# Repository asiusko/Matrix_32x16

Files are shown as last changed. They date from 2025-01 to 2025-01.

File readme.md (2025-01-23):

# The ESP32 based spectrum analyzer 32x16 LED matrix VU meter

### Main components:
 - Controller ESP32 WROOM-32D
 - Touch sensor TTP223B
 - Microphone Amplifier MAX9814 (with Auto Gain Control)
 - Rotary encoder
 - OLED I2C screen 128x64
 - WS2812B (two 16x16 zig-zag matrix) 

The controller can handle a few separate led strips or matrix. 
The current schema and code can handle 4 strips/matrix.

Please be careful with a power supply, it should provide enough power to supply the leds. 
Each LED draws about 50mA, when set to its full brightness. 
This means that for every 30 LEDs, the strip may draw as much as 1.5 A.
The matrix 16x32 contains 512 LEDs and needs 25A to show the full brightness.
You can restrict the max current for a strip/matrix on the program level. 

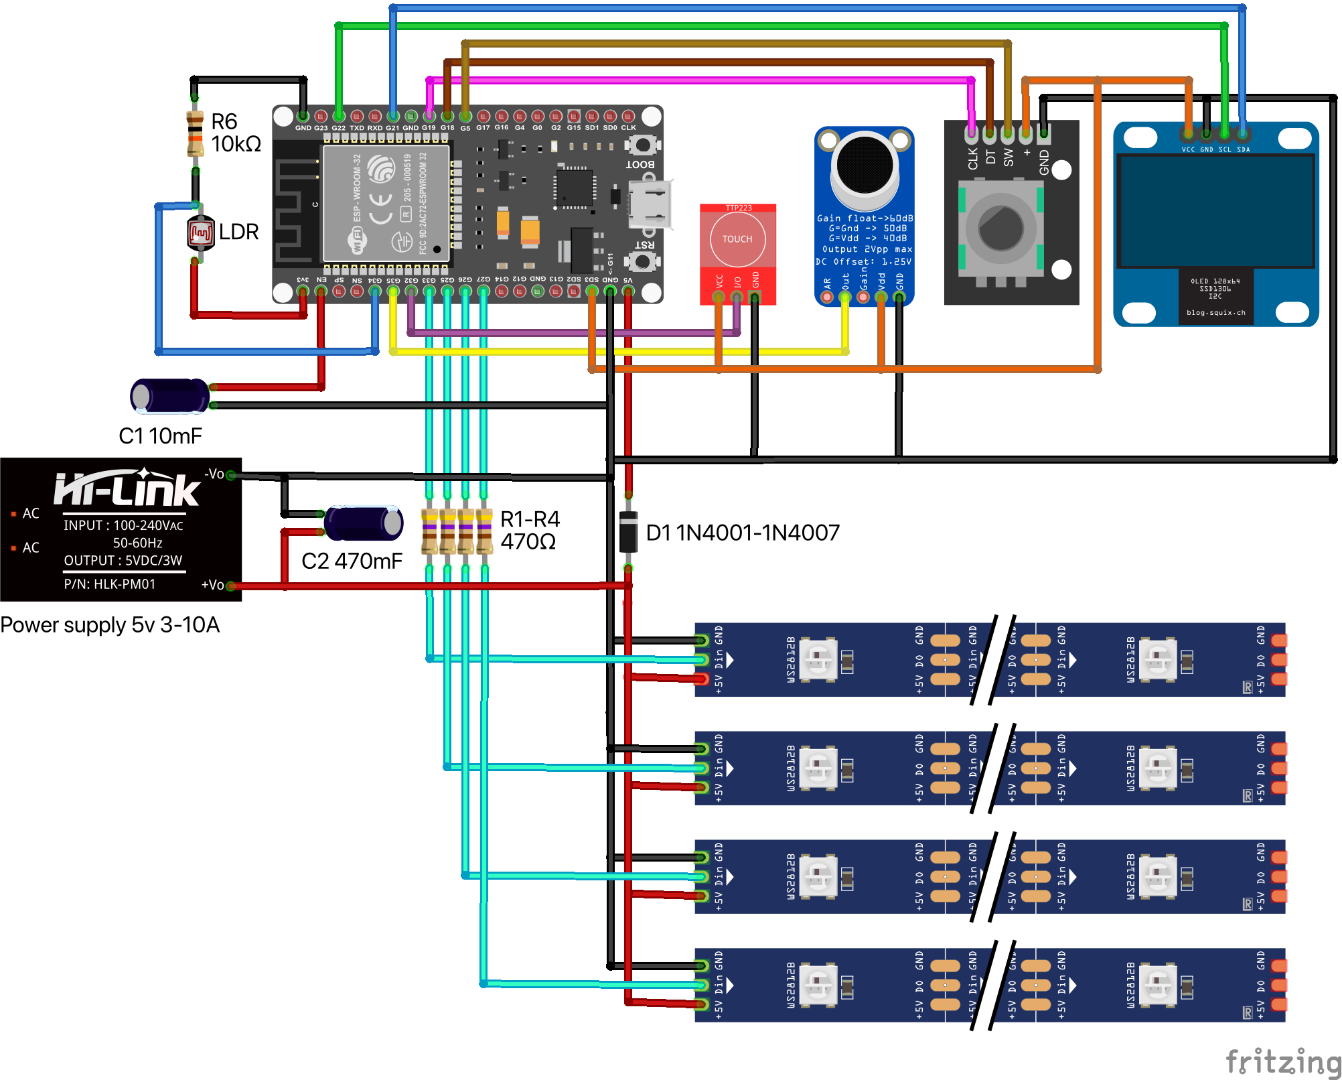
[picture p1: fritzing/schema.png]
Main schema


- Capacitor C1 10mF - to avoid the boot btn press during firmware uploading.
- Capacitor C2 470mf - power supply noise filter.
- Resistors R1-R4 330Ω–470Ω - protection resistors, place the resistors as close as possible to the ESP32 pin for maximum effectiveness (voltage spikes can damage the first LED in the chain or cause erratic behavior)  
- Diode D1 1N4001-1N4007 - to prevent LEDs power supply from USB port during firmware update.
- R6-LDR resistors (voltage divider schema) are used take a light value on the analog pin. ADC resolution - 12 bits (values from 0 to 4095). 

### Images: 
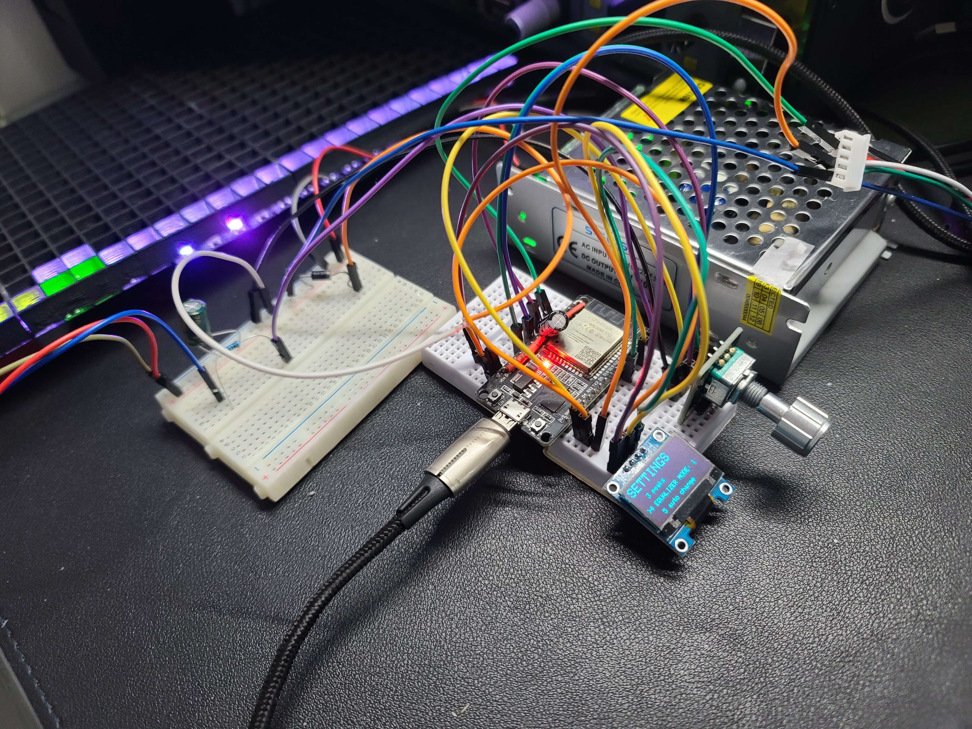
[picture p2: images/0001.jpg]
prototype

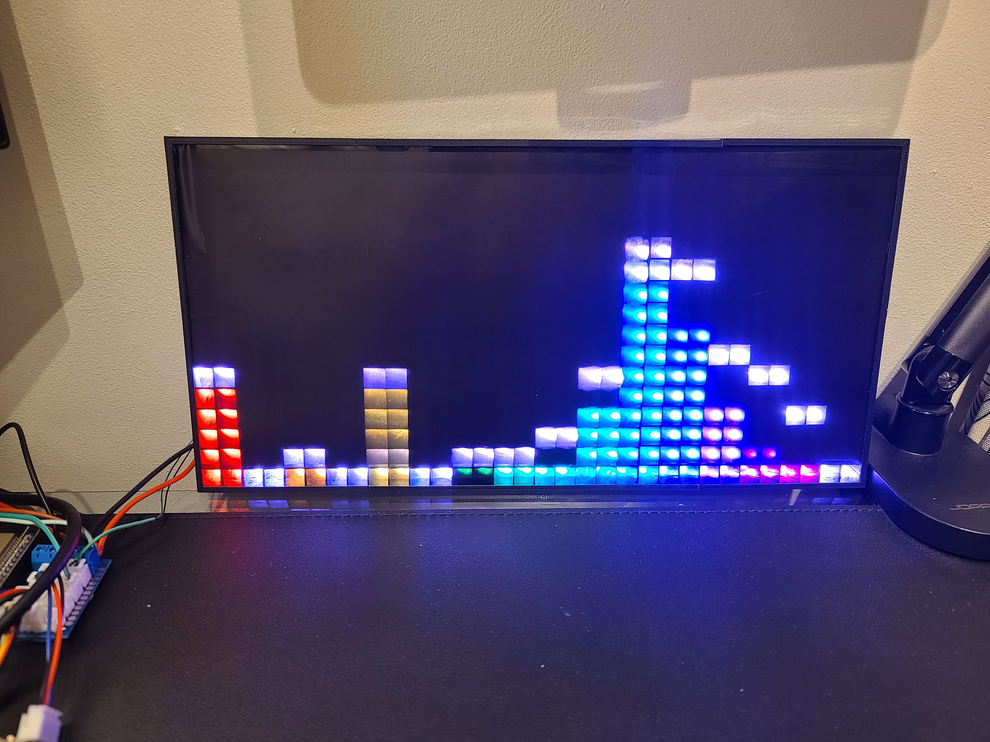
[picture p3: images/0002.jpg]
matrix

components

### Notes: 
- Please use **[sample_test.ino](tools/sampleTest/sample_test.ino)** and **[FFT.xlsx](tools/sampleTest/FFT.xlsx)** to calculate Band values based on the microcontroller ADC speed.
- If failed to mount SPIFFS file system. Run **[formatSPIFFS.ino](tools/formatSPIFFS/formatSPIFFS.ino)**
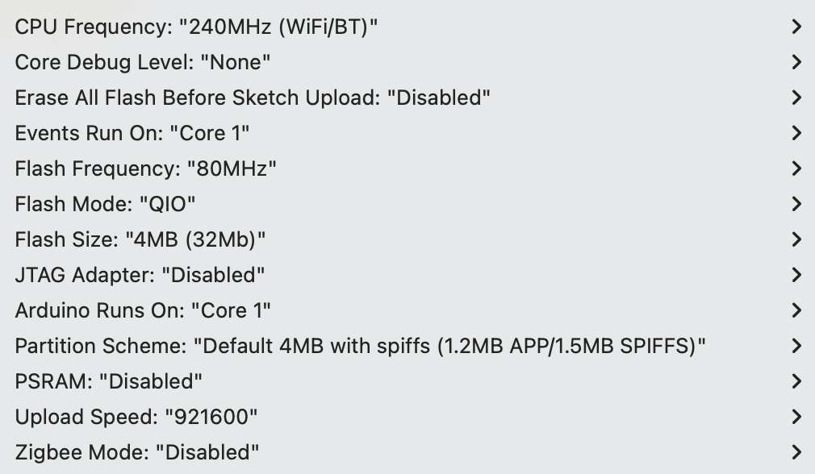
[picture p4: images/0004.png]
configuration
- ESP-WROOM-32D configuration 

### WiFi and WEB
- The ESP initially loads WiFi access point with predefined SSID and PASS check AP_WIFI_SSID and AP_WIFI_PASSWORD.
- In serial logs you can see the IP address, usually its 192.168.4.1
- To connect to the wifi just enter ssid and pass which will be saved in the internal memory for future connections.
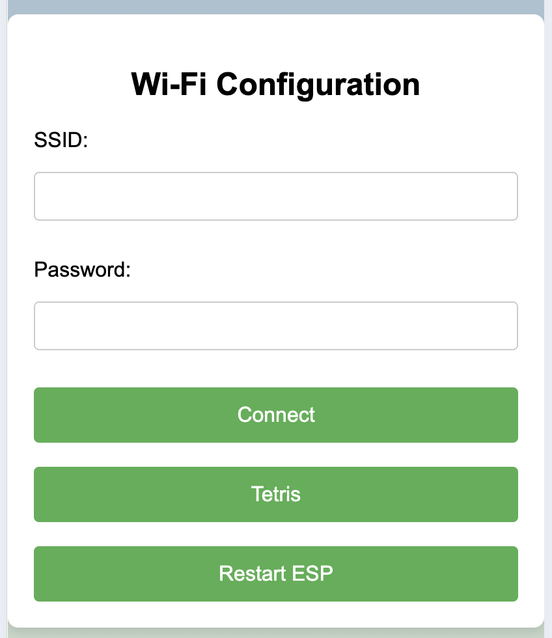
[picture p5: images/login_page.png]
login_page

- Tetris will start the game on the matrix and navigate to the control joystick, please use a mobile horizontal mode to display it correctly(TODO responsive design).
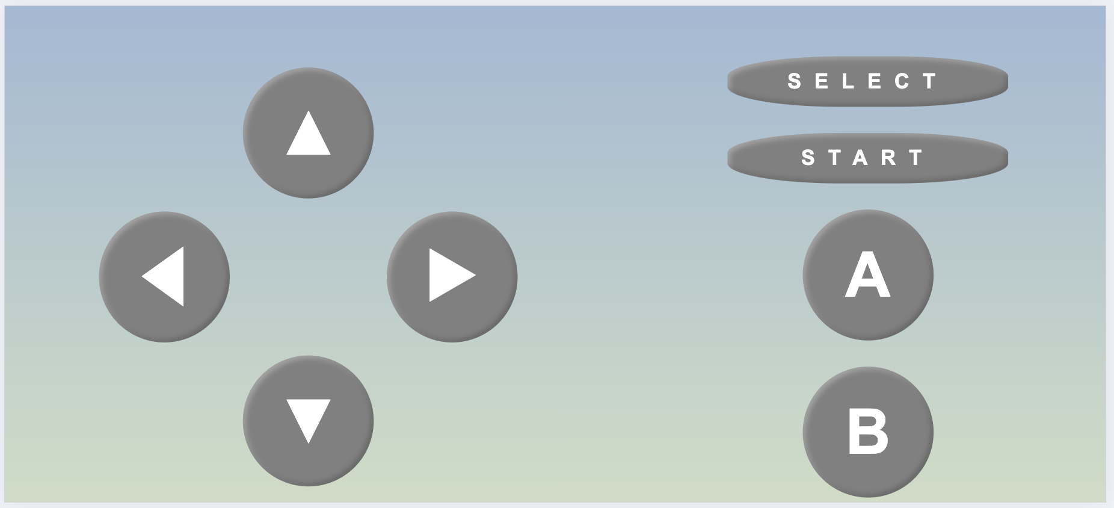
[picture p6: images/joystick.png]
joystick


### TODO:
- Sound output
- Vertical/Horizontal mode
- Connect with the home weather station
- Games
- More effects
- Responsive design and more controls from WEB
- Documentation

### License

This project is licensed under the Apache License, Version 2.0.

You are free to use, modify, and distribute this software under the terms of the Apache 2.0 License. See the [LICENSE](LICENSE.txt) file for details.

#### Key Points:
- **Attribution**: You must give proper credit to the original author(s).
- **Modifications**: If you modify the code, you must clearly indicate what changes were made.
- **No Liability**: The software is provided "as-is" without any warranty.

For more information, refer to the full [Apache 2.0 License](https://www.apache.org/licenses/LICENSE-2.0).

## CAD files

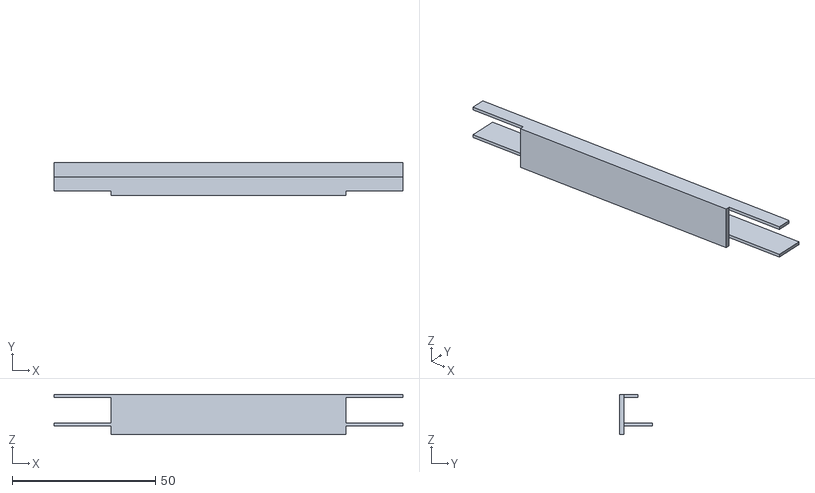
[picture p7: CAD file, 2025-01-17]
stl/32x16_frame_2.stl
122.0 x 11.5 x 14.0

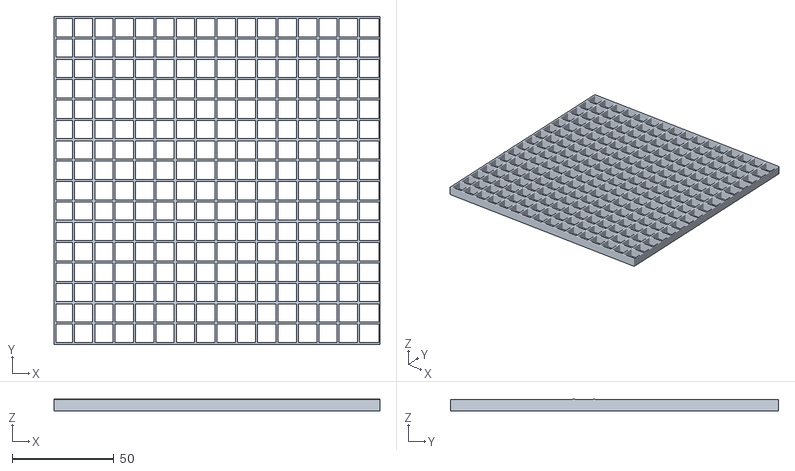
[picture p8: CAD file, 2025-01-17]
stl/32x16_matrix_grid.stl
160.0 x 161.0 x 6.00

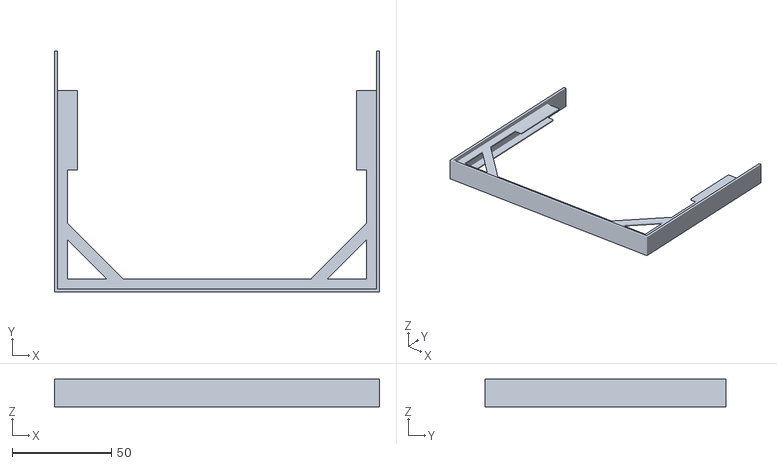
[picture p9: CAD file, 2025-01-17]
stl/32x16_frame_1.stl
164.0 x 121.5 x 14.0

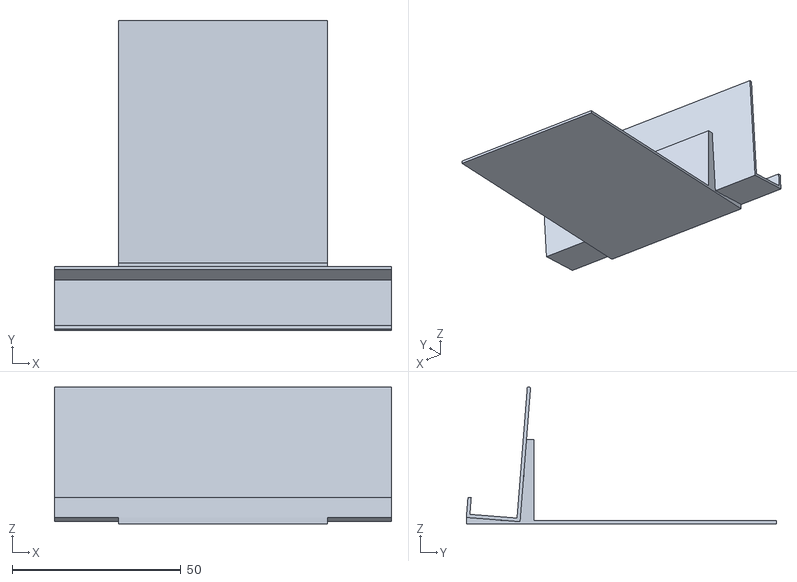
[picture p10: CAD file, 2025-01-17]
stl/32x16_holder.stl
100.0 x 92.1 x 40.6

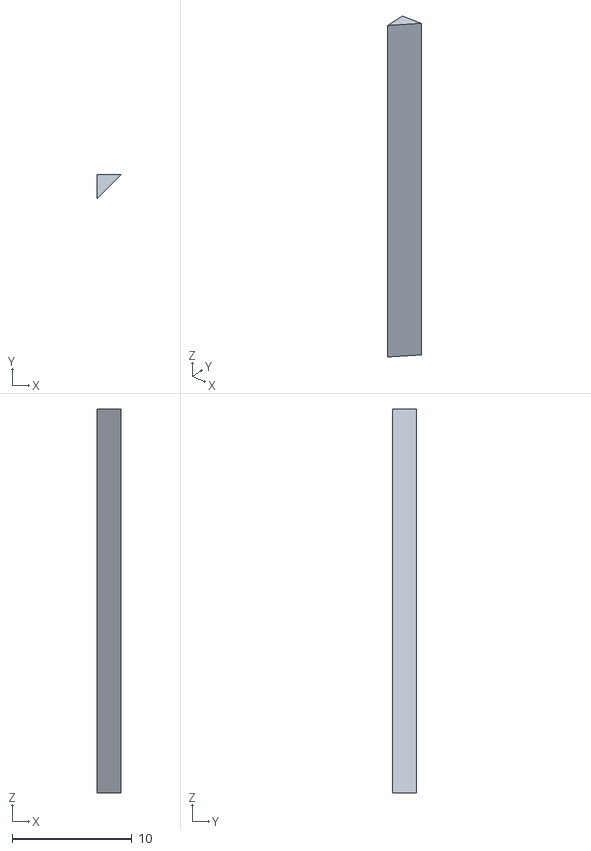
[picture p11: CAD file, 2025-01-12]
stl/32x16_box.stl
2.00 x 2.00 x 32.0

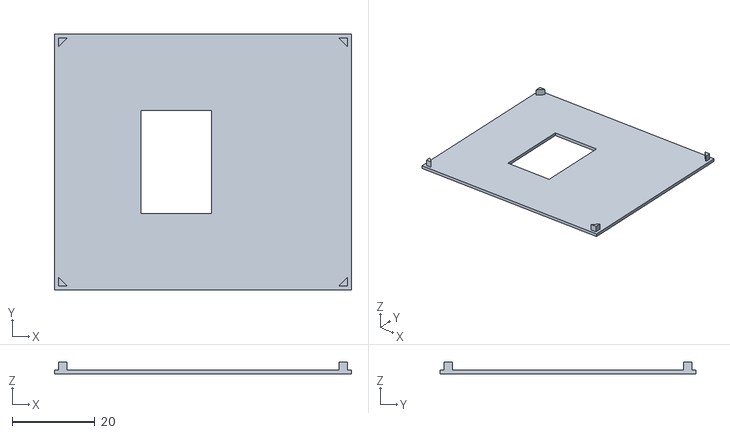
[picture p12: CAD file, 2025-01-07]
stl/32x16_box_top.stl
72.0 x 62.0 x 3.00

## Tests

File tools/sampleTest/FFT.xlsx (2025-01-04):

VU Meter FFT calculator
Complete the numbers in the green box. The table below will highlight in yellow showing your bands, and the low and high bin values to use in your code.
These values will give you a good starting point, but you may want to calibrate your bin numbers using a tone generator.
Sample Rate | 24000 | Hz | Number of samples per second, dependent on ADC sample rate (the value has to be lower than Max sampling frequency from the sample_test.ino)
Lowest frequency band | 200 | Hz | Center of lowest required band. Very low frequencies do not work well.
Highest frequency band | 12000 | Hz | Center of highest required band. Set this to below the Nyquist frequency
Number of samples | 512 |  | Must be power of 2 for MCU FFT libraries, bigger = more bins so more bands, but slower
Number of bands | 16 |  | Number of bands to display
Frequency mulitplier per band | 1.313842834 |  | What to multiply each band by to get the next band to give an exponential increase
Nyquist frequency | 12000 | Hz | Maximum frequency which can be detected
Bin width | 46.875 | Hz | Width of each frequency bin
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

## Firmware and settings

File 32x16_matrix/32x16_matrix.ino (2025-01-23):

#include <FastLED_NeoMatrix.h>
#include <Fonts/TomThumb.h>
#include <arduinoFFT.h>
#include <AiEsp32RotaryEncoder.h>
#include <Arduino.h>
#include <Adafruit_SSD1306.h>
#include <NTPClient.h>
#include <TimeLib.h>
#include <FS.h>
#include <SPIFFS.h>
#include <OneButton.h>
#include <Arduino_JSON.h>
#include <WiFi.h>
#include <WebServer.h>
#include <HTTPClient.h>
#include <WiFiUdp.h>

#include <wifiConfigPage.h>
#include <wifiJoystickPage.h>

#define BOARD_LED_PIN 2    // Built-in LED on most ESP32 boards 2 pin
#define AUDIO_IN_PIN 35    // Audio signal
#define SENSOR_BTN_PIN 32  // Touch btn

#define FFT_SAMPLES 512          // Must be a power of 2
#define FFT_SAMPLING_FREQ 24000  // Hz, must be 40000 or less due to ADC conversion time. Determines maximum frequency that can be analysed by the FFT Fmax=sampleF/2.
#define FFT_AMPLITUDE 10000      // Depending on your audio source level, you may need to alter this value. Can be used as a 'sensitivity' control.
#define FFT_FILTERED_NOISE 1000  // Used as a crude noise filter, values below this are ignored

#define LED_MAX_BANDS 16         // To change this, you will need to change the bunch of if statements describing the mapping from bins to bands
#define LED_STRIP_NUMBERS 4      // Amount of strips or matrix
#define LED_MAX_MILLI_AMPS 9000  // Be careful with the amount of power here if running from USB port
#define LED_VOLTS 5              // Usually 5 or 12

#define LED_1_PIN 33           // LED strip data
#define LED_1_COLOR_ORDER GRB  // If colours look wrong, play with this
#define LED_1_CHIPSET WS2812B  // LED strip type
#define LED_1_MATRIX_HEIGHT 16
#define LED_1_MATRIX_WIDTH 32
#define LED_1_QUANTITY (LED_1_MATRIX_WIDTH * LED_1_MATRIX_HEIGHT)   // Total number of LEDs
#define LED_1_BAR_WIDTH (LED_1_MATRIX_WIDTH / (LED_MAX_BANDS - 1))  // If width >= 8 light 1 LED width per bar, >= 16 light 2 LEDs width bar etc
#define LED_1_TOP_ELEMENT (LED_1_MATRIX_HEIGHT - 0)                 // Don't allow the bars to go offscreen

#define LED_2_PIN 25           // LED strip data
#define LED_2_COLOR_ORDER GRB  // If colours look wrong, play with this
#define LED_2_CHIPSET WS2812B  // LED strip type
#define LED_2_MATRIX_HEIGHT 14
#define LED_2_MATRIX_WIDTH 14
#define LED_2_QUANTITY (LED_2_MATRIX_WIDTH * LED_2_MATRIX_HEIGHT)   // Total number of LEDs
#define LED_2_BAR_WIDTH (LED_2_MATRIX_WIDTH / (LED_MAX_BANDS - 1))  // If width >= 8 light 1 LED width per bar, >= 16 light 2 LEDs width bar etc
#define LED_2_TOP_ELEMENT (LED_2_MATRIX_HEIGHT - 0)                 // Don't allow the bars to go offscreen

#define LED_3_PIN 26  // LED strip data

#define OLED_WIDTH 128
#define OLED_HEIGHT 64
#define TIMER_AUTO_CHANGE (60 * 1000)  // 60 second
#define TIMER_COLOR_CHANGE 10          // 10 millisecond
#define TIMER_DECAY_PEAK 60            // 60 millisecond
#define ROTARY_ENCODER_A_PIN 18        // CLK (A pin)
#define ROTARY_ENCODER_B_PIN 19        // DT (B pin)
#define ROTARY_ENCODER_BUTTON_PIN 5    // SW (button pin)
#define ROTARY_ENCODER_VCC_PIN -1      // VCC if microcontroller VCC (then set ROTARY_ENCODER_VCC_PIN -1)
#define ROTARY_ENCODER_STEPS 4         // depending on your encoder - try 1,2 or 4 to get expected behaviour
#define ROTARY_ENCODER_NOISE 10
#define ROTARY_ENCODER_MIN_VALUE 0
#define ROTARY_ENCODER_MAX_VALUE 15

#define AP_WIFI_SSID "MATRIX_32x16"    // Access Point SSID
#define AP_WIFI_PASSWORD "0123456789"  // Access Point Password

#define TIME_ZONE_OFFSET 3600            // +1 hour UK offset to UTC
#define CONFIRM_CLICK_ACTION_TIME 10000  // to confirm action
#define UPDATE_TIME_LOOP 1000

int PHOTO_RESISTOR_PIN = 34;  // by some reason must be an int value

AiEsp32RotaryEncoder rotaryEncoder = AiEsp32RotaryEncoder(ROTARY_ENCODER_A_PIN, ROTARY_ENCODER_B_PIN, ROTARY_ENCODER_BUTTON_PIN, ROTARY_ENCODER_VCC_PIN, ROTARY_ENCODER_STEPS);
byte encoderValue = 1;

// Settings
const byte BRIGHTNESS_SETTINGS[(ROTARY_ENCODER_MAX_VALUE + 1)] = { 0, 1, 2, 5, 10, 20, 40, 60, 80, 100, 125, 150, 175, 200, 225, 250 };
const String ENCODER_MODE[3] = { "DISPLAY", "SCROLL", "CHANGE VALUE" };
byte encoderMode = 0;
const String ENCODER_BTN_MODE[3] = { "SELECT LED", "SELECT", "CONFIRM" };
byte encoderBtnMode = 0;
const String SETTINGS[LED_STRIP_NUMBERS + 1] = { "LED 1", "LED 2", "LED 3", "LED 4", "LOGS" };  // LED_STRIP_NUMBERS + 1(Logs)
const byte settingsPropsLength = 7;
const String LED_SETTINGS[settingsPropsLength + 1] = { "MODE", "BRIGHTNESS", "PEAKS", "EQUALIZER MODE", "AUTO CHANGE", "NOISE LEVEL", "NIGHT MODE", "EXIT" };  // settingsPropsLength + 1(Exit)
const String LED_MODE[6] = { "EQUALIZER", "TIME", "LIGHT", "GAME", "FIRE 1", "FIRE 2" };

byte LED_SETTINGS_VALUE[LED_STRIP_NUMBERS][settingsPropsLength] = {
  { 0, 10, 1, 1, 0, 1, 1 },
  { 0, 10, 1, 1, 0, 1, 0 },
  { 0, 10, 1, 1, 0, 1, 0 },
  { 0, 10, 1, 1, 0, 1, 0 },
};
byte currentSetting = 0;
byte ledSettingProperty = 0;
byte newEncoderValue = LED_SETTINGS_VALUE[currentSetting][ledSettingProperty];


// Sampling and FFT
unsigned int sampling_period_us;
byte peak[LED_MAX_BANDS] = { 0, 0, 0, 0, 0, 0, 0, 0, 0, 0, 0, 0, 0, 0, 0, 0 };
int oldBarHeights[LED_MAX_BANDS] = { 0, 0, 0, 0, 0, 0, 0, 0, 0, 0, 0, 0, 0, 0, 0, 0 };
int bandValues[LED_MAX_BANDS] = { 0, 0, 0, 0, 0, 0, 0, 0, 0, 0, 0, 0, 0, 0, 0, 0 };
double vReal[FFT_SAMPLES];
double vImag[FFT_SAMPLES];
unsigned long newTime;
ArduinoFFT<double> FFT = ArduinoFFT<double>(vReal, vImag, FFT_SAMPLES, FFT_SAMPLING_FREQ);

// Create OLED display object
Adafruit_SSD1306 display(OLED_WIDTH, OLED_HEIGHT, &Wire, -1);

// FastLED
CRGB ledsConfiguration1[LED_1_QUANTITY];

DEFINE_GRADIENT_PALETTE(purple_gp){
  0, 0, 212, 255,   //blue
  255, 179, 0, 255  //purple
};
DEFINE_GRADIENT_PALETTE(outrun_gp){
  0, 141, 0, 100,    //purple
  127, 255, 192, 0,  //yellow
  255, 0, 5, 255     //blue
};
DEFINE_GRADIENT_PALETTE(greenblue_gp){
  0, 0, 255, 60,     //green
  64, 0, 236, 255,   //cyan
  128, 0, 5, 255,    //blue
  192, 0, 236, 255,  //cyan
  255, 0, 255, 60    //green
};
DEFINE_GRADIENT_PALETTE(redyellow_gp){
  0, 200, 200, 200,   //white
  64, 255, 218, 0,    //yellow
  128, 231, 0, 0,     //red
  192, 255, 218, 0,   //yellow
  255, 200, 200, 200  //white
};
CRGBPalette16 purplePal = purple_gp;
CRGBPalette16 outrunPal = outrun_gp;
CRGBPalette16 greenbluePal = greenblue_gp;
CRGBPalette16 heatPal = redyellow_gp;
uint8_t colorTimer = 0;

const int LED_TOP_ELEMENTS[LED_STRIP_NUMBERS] = { LED_1_TOP_ELEMENT, LED_2_TOP_ELEMENT, LED_1_TOP_ELEMENT, LED_1_TOP_ELEMENT };
const int LED_BAR_WIDTHS[LED_STRIP_NUMBERS] = { LED_1_BAR_WIDTH, LED_2_BAR_WIDTH, LED_1_BAR_WIDTH, LED_1_BAR_WIDTH };
const int LED_MATRIX_HEIGHTS[LED_STRIP_NUMBERS] = { LED_1_MATRIX_HEIGHT, LED_2_MATRIX_HEIGHT, LED_1_MATRIX_HEIGHT, LED_1_MATRIX_HEIGHT };
const int LED_MATRIX_WIDTHS[LED_STRIP_NUMBERS] = { LED_1_MATRIX_WIDTH, LED_2_MATRIX_WIDTH, LED_1_MATRIX_WIDTH, LED_1_MATRIX_WIDTH };

// FastLED_NeoMatrix - see https://github.com/marcmerlin/FastLED_NeoMatrix
FastLED_NeoMatrix* matrix = new FastLED_NeoMatrix(ledsConfiguration1, LED_1_MATRIX_WIDTH, LED_1_MATRIX_HEIGHT, 1, 1,
                                                  NEO_MATRIX_TOP + NEO_MATRIX_LEFT + NEO_MATRIX_TOP + NEO_MATRIX_LEFT + NEO_MATRIX_COLUMNS + NEO_MATRIX_ZIGZAG);

// Define NTP Client to get time
WiFiUDP ntpUDP;
NTPClient timeClient(ntpUDP, "europe.pool.ntp.org", 0);

// Sensor button
OneButton sensorButton(SENSOR_BTN_PIN, false);
bool isReadyToResetWiFi = false;
bool isLoggerActive = false;
unsigned long resetCounterMillis = 0;

// WiFi connection
bool connectionDefined = false;
String savedSsid = "";
String savedPass = "";
WebServer server(80);
HTTPClient http;
WiFiClient client;

String timeString = "";
String gameBtnAction = "";

// has to be before setup()
void IRAM_ATTR readEncoderISR() {
  rotaryEncoder.readEncoder_ISR();
}

void setup() {
  // Wait for 1 second before initializing Serial to start hardware SPIFFS
  delay(2000);
  Serial.begin(115200);

  // Initialize file system
  if (!SPIFFS.begin()) {
    logLn("Failed to mount file system");
    return;
  }

  pinMode(BOARD_LED_PIN, OUTPUT);
  digitalWrite(BOARD_LED_PIN, HIGH);

  // Initialize BUTTON
  sensorButton.attachClick(sensorButtonSingleClick);
  sensorButton.attachDoubleClick(sensorButtonDoubleClick);
  sensorButton.attachLongPressStop(sensorButtonLongPress);

  // Initialize OLED display (with I2C address 0x3C)
  if (!display.begin(SSD1306_SWITCHCAPVCC, 0x3C)) {
    Serial.println("SSD1306 allocation failed");
    for (;;)
      ;
  }
  display.clearDisplay();
  renderOLED();

  // rotary encoder
  rotaryEncoder.begin();
  rotaryEncoder.setup(readEncoderISR);
  rotaryEncoder.setBoundaries(ROTARY_ENCODER_MIN_VALUE, ROTARY_ENCODER_MAX_VALUE, true);  //minValue, maxValue, circleValues true|false (when max go to min and vice versa)

  /*Rotary acceleration introduced 25.2.2021.
   * in case range to select is huge, for example - select a value between 0 and 1000 and we want 785
   * without acceleration you need long time to get to that number
   * Using acceleration, faster you turn, faster will the value raise.
   * For fine tuning slow down.
   */
  rotaryEncoder.disableAcceleration();  //acceleration is now enabled by default - disable if you dont need it
                                        //rotaryEncoder.setAcceleration(250); //or set the value - larger number = more acceleration; 0 or 1 means disabled acceleration


  // LED
  FastLED.addLeds<LED_1_CHIPSET, LED_1_PIN, LED_1_COLOR_ORDER>(ledsConfiguration1, LED_1_QUANTITY).setCorrection(TypicalSMD5050);
  FastLED.setMaxPowerInVoltsAndMilliamps(LED_VOLTS, LED_MAX_MILLI_AMPS);
  FastLED.setBrightness(BRIGHTNESS_SETTINGS[LED_SETTINGS_VALUE[currentSetting][1]]);
  FastLED.clear();

  sampling_period_us = round(1000000 * (1.0 / FFT_SAMPLING_FREQ));

  logLn("SPIFFS is mounted");
  connectionDefined = false;                      // Initial Connection state before checking saved data
  File configFile = SPIFFS.open("/config.json");  // Read Configuration data from the JSON file

  if (!configFile) {
    logLn("Failed to open config file for reading");
  } else {
    String jsonStr = configFile.readString();  // Read the contents of the file into a string
    Serial.println("jsonStr");
    Serial.println(jsonStr);
    configFile.close();                      // Close the file to reduce memory usage
    JSONVar jsonData = JSON.parse(jsonStr);  // Deserialize the JSON string into an Arduino_JSON object

    if (!JSON.typeof(jsonData) || JSON.typeof(jsonData) == "undefined") {
      logLn("Failed to parse JSON data");
    } else {
      const char* ssidChar = jsonData["ssid"];
      const char* passChar = jsonData["pass"];

      savedSsid = String(ssidChar);
      savedPass = String(passChar);

      connectionDefined = savedSsid.length() && savedPass.length() ? true : false;
      logLn("connectionDefined: " + String(connectionDefined));
    }
  }

  // If no Config, run initial page with a wifi form
  // Setting the AP Mode with SSID, Password, and Max Connection Limit
  if (!connectionDefined) {
    logLn("Create a WiFi AP");

    if (WiFi.softAP(AP_WIFI_SSID, AP_WIFI_PASSWORD) == true) {
      logLn("WEB: " + WiFi.softAPIP().toString());
      logLn("WIFI: " + String(WiFi.softAPSSID()) + "   PASS: " + String(AP_WIFI_PASSWORD));
      WiFi.mode(WIFI_AP);
    } else {
      logLn("Unable to Create AP");
    }
  } else {
    // Connect to Wi-Fi
    if (connectToWifi(savedSsid, savedPass)) {
      // Start NTP client
      timeClient.begin();
      delay(1000);         // wait time from server
      updateTimeOffset();  // set summer/winter time
      timeClient.update();
      timeString = timeClient.getFormattedTime();
      Serial.println(WiFi.localIP());
    };
  }

  startServerListener();
}

void loop() {
  server.handleClient();
  rotaryLoop();

  for (byte ledStripNumber = 0; ledStripNumber < LED_STRIP_NUMBERS; ledStripNumber++) {
    // no ways to manage ledsConfiguration and matrix in the arrays, esp32 memory allocation issue due to the huge objects
    // TODO investigate and fix, get ledsConfiguration and matrix by iterator
    switch (LED_SETTINGS_VALUE[ledStripNumber][0]) {
      case (0):  // Equalizer
        switch (ledStripNumber) {
          case (0):
            buildEqualizer(ledStripNumber, ledsConfiguration1, matrix);
            break;
        }
        break;
      case (1):  // Time
        switch (ledStripNumber) {
          case (0):
            buildTime(ledStripNumber, timeString, matrix);
            break;
        }
        break;
      case (2):  // Light
        switch (ledStripNumber) {
          case (0):
            buildLight(ledStripNumber, matrix);
            break;
        }
        break;
      case (3):  // Game
        buildGame(ledStripNumber, ledsConfiguration1, matrix, gameBtnAction);
        gameBtnAction = " ";
        break;
      case (4):  // Full screen Fireplace
        fireplace(ledStripNumber, ledsConfiguration1, matrix);
        delay(30);
        break;
      case (5):  // Fireplace
        drawCampfire(ledStripNumber, ledsConfiguration1, matrix);
        delay(30);
        break;
    }

    FastLED.show();
  }

  EVERY_N_MILLISECONDS(TIMER_DECAY_PEAK) {
    for (byte band = 0; band < LED_MAX_BANDS; band++)
      if (peak[band] > 0) peak[band] -= 1;
    colorTimer++;
  }

  EVERY_N_MILLISECONDS(TIMER_COLOR_CHANGE) {
    colorTimer++;
  }

  // autochange
  EVERY_N_MILLISECONDS(TIMER_AUTO_CHANGE) {
    for (byte led = 0; led < LED_STRIP_NUMBERS; led++) {
      if (LED_SETTINGS_VALUE[led][4]) {
        // peaks
        LED_SETTINGS_VALUE[led][2] = random(1, 3);
        // equalizerMode
        LED_SETTINGS_VALUE[led][3] = random(1, 6);
      }
    }
  }

  // update time
  EVERY_N_MILLISECONDS(UPDATE_TIME_LOOP) {
    timeString = timeClient.getFormattedTime();

    if (LED_SETTINGS_VALUE[0][6]) {
      int photoResistorValue = analogRead(PHOTO_RESISTOR_PIN);  // 0 - 4095
      int newBrightness = map(photoResistorValue, 0, 4095, 1, 12);
      FastLED.setBrightness(BRIGHTNESS_SETTINGS[newBrightness]);
    }
  }

  EVERY_N_MILLISECONDS(CONFIRM_CLICK_ACTION_TIME) {
    if (isReadyToResetWiFi) {
      isReadyToResetWiFi = false;

      logLn("Reset canceled by time");
    }
  }

  EVERY_N_MILLISECONDS(UPDATE_TIME_LOOP * 60) {
    timeClient.update();
  }
}

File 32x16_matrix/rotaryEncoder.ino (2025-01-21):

void rotaryOnButtonClick() {
  static unsigned long lastTimePressed = 0;
  //ignore multiple press in that time milliseconds
  if (millis() - lastTimePressed < ROTARY_ENCODER_NOISE) {
    return;
  }

  lastTimePressed = millis();

  if (ledSettingProperty == settingsPropsLength) {
    // exit to change led level
    encoderMode = 0;
    encoderBtnMode = 1;
    ledSettingProperty = 0;
    rotaryEncoder.setEncoderValue(currentSetting);
  } else if (encoderBtnMode) {
    // CONFIRM changed value
    rotaryEncoder.setEncoderValue(ledSettingProperty);
    encoderMode = 1;
    encoderBtnMode = 0;
  } else {
    // SELECT
    rotaryEncoder.setEncoderValue(LED_SETTINGS_VALUE[currentSetting][ledSettingProperty]);
    encoderMode = 2;
    encoderBtnMode = 1;
  }

  renderOLED();
}

void changeLed(byte value) {
  currentSetting = value;

  currentSetting = currentSetting > LED_STRIP_NUMBERS ? LED_STRIP_NUMBERS : currentSetting;
  currentSetting = currentSetting < 0 ? 0 : currentSetting;
}

void changeMode(byte value) {
  ledSettingProperty = value;

  ledSettingProperty = ledSettingProperty > settingsPropsLength ? settingsPropsLength : ledSettingProperty;
  ledSettingProperty = ledSettingProperty < 0 ? 0 : ledSettingProperty;

  newEncoderValue = LED_SETTINGS_VALUE[currentSetting][ledSettingProperty];
}

byte changeModeValue(byte value) {
  switch (ledSettingProperty) {
    case 0:  // LED_MODE
      value = value > 5 ? 5 : value;
      value = value < 0 ? 0 : value;
      break;
    case 1:  // BRIGHTNESS
      FastLED.setBrightness(BRIGHTNESS_SETTINGS[value]);
      break;
    case 2:  // PEAKS
      value = value > 3 ? 3 : value;
      value = value < 1 ? 1 : value;
      break;
    case 3:  // EQUALIZER_MODE
      value = value > 6 ? 6 : value;
      value = value < 1 ? 1 : value;
      break;
    case 4:  // AUTO_CHANGE
      value = LED_SETTINGS_VALUE[currentSetting][ledSettingProperty] == 1 ? 0 : 1;
      break;
    case 5:  // NOISE_LEVEL
      value = value > 0 ? value : 1;
      break;
    case 6:  // NIGHT MODE
      value = LED_SETTINGS_VALUE[currentSetting][ledSettingProperty] == 1 ? 0 : 1;
    case 7:  // EXIT
      break;
  }

  if (ledSettingProperty != 7) LED_SETTINGS_VALUE[currentSetting][ledSettingProperty] = value;

  return value;
}

void rotaryLoop() {
  if (rotaryEncoder.isEncoderButtonClicked()) {
    rotaryOnButtonClick();
  } else if (rotaryEncoder.encoderChanged()) {
    byte encoderValue = rotaryEncoder.readEncoder();

    switch (encoderMode) {
      // Select LED
      case (0):
        changeLed(encoderValue);
        encoderBtnMode = 1;
        break;
      // Scroll Settings
      case (1):
        changeMode(encoderValue);
        encoderBtnMode = 0;
        break;
      // Change value
      case (2):
        newEncoderValue = changeModeValue(encoderValue);
        encoderBtnMode = 1;
        break;
    }

    renderOLED();
  }
}

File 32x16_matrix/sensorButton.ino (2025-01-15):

void sensorButtonSingleClick() {
  // cancel actions - single click
  if (isReadyToResetWiFi) {
    isReadyToResetWiFi = false;
    logLn("Reset canceled");
    blinkLed();
    return;
  }
}

void sensorButtonDoubleClick() {
  // confirm actions - double click
  if (isReadyToResetWiFi) {
    isReadyToResetWiFi = false;

    logLn("Resetting WiFi data...");
    resetSavedData();
    blinkLed(2);
    logLn("Restart ESP");

    return;
  }
}

void sensorButtonLongPress() {
  isReadyToResetWiFi = true;
  resetCounterMillis = millis();
  logLn("Resetting WiFi data");
  logLn("Double click - Yes, Single Click - No");
}

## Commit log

2025-01-04 Added Matrix, sampleTest, xls with FFT
    [FFT.xlsx, schema.fzz]
2025-01-07 Added stl files
    [32x16_box.stl, 32x16_box_top.stl, 32x16_matrix_back_3.stl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]
2025-01-12 Adds multi LED strip/matrix support.
    [32x16_box.stl]
2025-01-14 multi led fixes
2025-01-14 Added wifi config. Added web time. Added sensor touch.
    [FFT.xlsx]
2025-01-17 new stl files
    [32x16_frame_1.stl, 32x16_frame_2.stl, 32x16_holder.stl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]
2025-01-21 Added fireplace effects. Added LDR sensor. Updated FZZ schema.
    [schema.fzz]
2025-01-21 Updated FZZ files
    [schema.fzz]
